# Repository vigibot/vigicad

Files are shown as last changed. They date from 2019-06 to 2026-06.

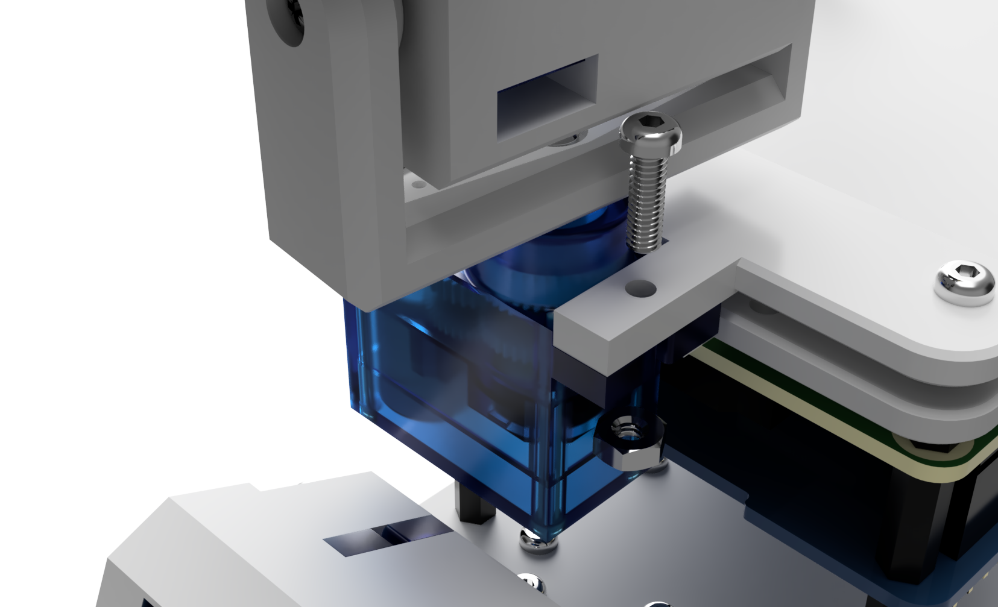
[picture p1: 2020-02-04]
images/Minus assembly/Final assembly-8.png

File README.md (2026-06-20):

# Build Your Own Vigibot Raspberry Pi Robot

## Description

[Vigibot](https://www.vigibot.com/) is a platform that enables remote control of Raspberry Pi-based robots over the Internet, with live video streaming and real-time interaction.

This repository contains the CAD files, PCB files, and documentation required to build the reference robot platform used within the Vigibot ecosystem.

## Robot Versions

### Minus 2S (Current Version)

The **Minus 2S** is the latest generation of our 4WD robot platform, featuring a gripper and a pan-tilt camera head. It has been redesigned around custom PCBs to simplify assembly, improve reliability, and provide a cleaner overall build.

Compared to the previous version, the Minus 2S uses a **2-cell (2S) Li-ion/LiPo battery architecture** and the new **Vigi UPS V3** power management board.

Key advantages of the 2S architecture include:

- Higher available power for motors and peripherals

- Lower current for the same power output, reducing voltage drops and cable losses

- Improved stability during motor acceleration and under heavy load

- Better support for power-demanding accessories such as LiDARs, USB devices, and 4G modems

- Increased efficiency of the overall power system

The integration of the **Vigi UPS V3** further enhances the platform by providing robust power management for the Raspberry Pi and onboard electronics, improving overall system stability and reliability.

### Minus 1S (Legacy / Deprecated)

The **Minus 1S** is the previous generation of the robot platform and is now considered legacy hardware.

It uses a single-cell (1S) battery architecture and an earlier power management design. While still functional, it offers lower available power and more limited expansion capabilities compared to the Minus 2S platform.

## Repository Contents

Each repository includes the resources required to build the corresponding robot platform:

- CAD files for 3D-printed parts

- PCB design files

- Assembly documentation

- Hardware resources related to the robot platform

## Notes

- This project is actively evolving.

- Additional documentation, assembly guides, and build instructions will be added over time.

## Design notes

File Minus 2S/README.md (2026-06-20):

# Build Your Own Minus 2S Robot

## Description

The **Minus 2S** is the latest generation of our 4WD mobile robot platform, featuring a robotic gripper, a pan-tilt camera head, infrared night vision, and full compatibility with the Vigibot remote-control platform.

Designed around custom PCBs, a 2S battery architecture, and the new **Vigi UPS V3**, it offers simplified assembly, improved reliability, and enhanced power capabilities compared to the previous Minus 1S platform.

All the parts required to build the robot are available in the following kit:  
[Minus 2S Kit](https://www.robot-maker.com/shop/kits-robots/284-kit-minus-2s-284.html)

## Parts List (included in the kit)

### Standard Components

- Raspberry Pi 3B+

- 32 GB microSD card

- N20 DC gear motors with pogo-pin connectors ×4

- 32 mm wheels ×4

- 2S1P battery pack

- 3 W mini speaker

- Raspberry Pi Camera with IR-cut filter

- 9 g 270° servo motor ×1

- 9 g 180° servo motors ×3

- 20 cm Raspberry Pi ribbon cable

- Raspberry Pi spacer (2×20 long female header)

### PCB Set

- Vigi UPS V3 Bottom PCB

- Audio Top PCB

- IR LED Head PCB

- Right Side PCB

- Left Side PCB

### 3D Printed Parts Set

- Minus 2S Base

- Battery Holder

- Head and Gripper Mount

- Gripper Body

- Right Gripper Finger

- Left Gripper Finger

- Head Mount

- Head

### Screws and Standoffs Set

- M2.5 × 5 mm nylon male standoffs ×4

- M2.5 × 4 mm nylon screws ×4

- M2.5 nylon nuts ×4

- M2 × 5 mm nylon male standoffs ×2

- M2 × 6 mm metal screws ×13

- M2 × 14 mm metal screws ×6

- M2 × 12 mm metal screws ×2

- M2 × 8 mm metal screws ×7

- M2 nylon nuts ×6

## Optional Add-ons

You can customize your robot with many accessories :

- [LED Rotating Beacon](https://www.robot-maker.com/shop/composants/489-gyrophare-led-489.html)

- [LD06 LiDAR](https://www.robot-maker.com/shop/capteurs/468-lidar-ld06-468.html)

- [Mecanum wheels 48mm](https://www.robot-maker.com/shop/elements-mecaniques/471-roues-mecanum-48mm-de-diametre-471.html)

- Magnetic charging station 
  
  - [Magnetic cable](https://www.robot-maker.com/shop/alimentation/335-cable-usb-magnetique.html)
  - [Magnetic USB C Plug](https://www.robot-maker.com/shop/alimentation/336-embout-magnetique-micro-usb-336.html)

- 4G USB modem with right-angle USB adapter and 3D-printed holder

## Notes

- This project is currently a work in progress. Additional documentation and assembly instructions will be added soon.

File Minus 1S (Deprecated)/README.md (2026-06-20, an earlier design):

# Make your own Vigibot.com raspberry PI robot

## Minus Raspberry PI robot CAD files

### All pieces assembled for the standard Vigibot

### Parts list

#### Core assembly

- Raspberry PI 2 / Raspberry PI 3 / Raspberry PI 3 A+ / Raspberry PI 3 B+ / Raspberry PI 4

- An aftermarket *wide-angle lens* camera module v1 clone is highly recommended
  
  - The "genuine" camera module v1 or v2 use pinhole lens and are bad for first person view piloting
  - There is only one camera module v1 clone that combines a *wide-angle lens* and a motorized IR-cut filter at time of writing
    - https://www.robot-maker.com/shop/capteurs/311-camera-raspberry-pi.html  (fast delivery)
    - https://www.aliexpress.com/item/32957419294.html
  - It is better to have the *wide-angle lens* than the motorized IR-cut filter without the wide-angle lens

- 30cm Raspberry PI camera cable
  
  - https://www.robot-maker.com/shop/composants/329-nappe-raspberry-pi.html#/92-longueur-30cm

- A reliable Raspberry PI UPS hat board, there is only one at time of writing
  
  - The Geekworm / U-geek UPS Hat V3
    - https://www.amazon.fr/gp/product/B089NF1NHS
    - https://fr.aliexpress.com/item/4001113371912.html

- 1S Batterie with BMS included
  -

- 3D printed parts, screws, nuts and standoffs 
  
  - Full kit : https://www.robot-maker.com/shop/kits-robots/425-kit-chassis-4wd-minus-425.html
  - List :
    - 3D printed parts : 4  ( Top, middle, bottom and rear plate )
    - 12mm length M2.5 male standoffs between the Raspberry PI and UPS hat board : 4
    - 25mm length M2.5 male standoffs between the UPS hat board and middle plate : 4
    - 10mm length M2.5 female standoffs between the middle plate and bottom plate : 4
    - 5mm length M2.5 male standoffs between the Raspberry PI board and top plate : 4
    - 6 mm M2.5 screw : 10 ( 4 top plate / 4 bottom plate / 2 middle plate)
    - 8 or 10 mm M2.5 screw to fix motor board : 2 
    - M2.5 nut : 6 ( 4 for the motor board / 2 middle plate)
    - 8mm length M2 screw to fix the back plate on the middle plate : 3 
    - M2 nut : 3

#### Motorization

- Four Pololu 100:1 micro metal gearmotor HP 6V
  - https://www.robot-maker.com/shop/moteurs-et-actionneurs/384-moteur-pololu-300-rpm.html (provided with cable you need to solder, but can be provided soldered)
  - https://www.pololu.com/product/1101
- Four Pololu micro metal gearmotor extended bracket ( provided with screws and nuts)
  - https://www.robot-maker.com/shop/elements-mecaniques/385-support-moteur-pololu-long.html
  - https://www.pololu.com/product/1089
- Four Pololu wheel 40×7mm
  - https://www.robot-maker.com/shop/elements-mecaniques/346-roue-pololu-40mm.html  
  - https://www.pololu.com/product/1454
- Feetech 2ch motor controller (provided with cables) 
  - https://www.robot-maker.com/shop/drivers-d-actionneurs/280-driver-convertisseur-moteur-cc-servomoteur.html

#### Head assembly

- Two "SG90" type micro servo
  
  - 270° servo is highly recommended for the pan axis : 1
    
    - https://www.robot-maker.com/shop/moteurs-et-actionneurs/370-servomoteur-9g-270-370.html
  
  - 180° servo is good for the tilt axis : 1
    
    - https://www.robot-maker.com/shop/moteurs-et-actionneurs/18-servomoteur-9g-18.html

- 3D printed parts, screws, nuts and standoffs
  
  - Full kit : https://www.robot-maker.com/shop/kits-robots/88-kit-tourelle-pan-tilt-88.html
  - List :
    - 3D printed parts : 3 or 4 (Smiling head, pan plate, tilt bracket, and 4th is an optional protection to protect camera lens)
    - 10mm or 12mm length M2.5 screw  : 2 ( to fix pan plate to the rest of the robot)
    - M2.5 nut : 2
    - 5 or 6 mm M2 screw : 1 
    - 8 mm M2 screw : 2  (to fix 270° servo on the pan plate)
    - 14 or 16 mm M2 screw : 2 ( to fix 180° servo in the head)
    - 20 mm M2 screw : 4 (for camera assembly on the head)
    - M2 nut : 10 (8 for the camera, 2 to fix the servo on the pan plate)

#### Clamp assembly

- 180° servo SG90 servo : 2
  
  - https://www.robot-maker.com/shop/moteurs-et-actionneurs/18-servomoteur-9g-18.html

- 3D printed parts, screws and nuts
  
  - Full kit : https://www.robot-maker.com/shop/kits-robots/423-kit-pince-minus-423.html
  - List :
    - 3D printed parts : 4
    - 5 or 6 mm M2 screw : 1
    - 8 mm M2 screw : 3
    - 10 mm M2 screw : 1
    - 14 mm M2 screw : 5
    - M2 nut : 2

#### Lateral arms

- 180° servo SG90 servo : 2
  
  - https://www.robot-maker.com/shop/moteurs-et-actionneurs/18-servomoteur-9g-18.html

- 3D printed parts, screws and nuts
  
  - Full kit : https://www.robot-maker.com/shop/kits-robots/424-kit-bras-lateraux-minus-424.html
  - List :
    - 3D printed parts : 4 (left and right servo holder, and left and right lateral arms)
    - 8 mm M2 screw : 2 (to fix lateral arms on the servo)
    - 14 mm M2.5 screw : 2 (to fix servo holders on the rest of the robot it replaces 8mm M2.5 screws)
    - M2.5 nut : 2 (to fix servo holders on the rest of the robot, use 8mm M2.5 screws previously removed, wich was already on your robot) 
    - Note : use the long screws provided with servomotors to fix the servomotors on the servo holder

#### Charge station assembly

- A USB magnetic cable with magnetic plug
  - https://www.robot-maker.com/shop/alimentation/335-cable-usb-magnetique.html
  - https://www.robot-maker.com/shop/alimentation/336-embout-magnetique-micro-usb-336.html
- 3D printed part :
  - https://www.robot-maker.com/forum/topic/13134-station-de-charge-pour-robot-de-type-minus

#### Optionnal add ons

- 40mm fan for the top plate  https://www.amazon.fr/gp/product/B07D5QBFLK/ref=ppx_yo_dt_b_asin_title_o01_s00 ( use top plate with fan hole in this case)
- Leds to show if someone is using the robot or not
- Cables to manually control the IR led state on the camera

### Notes

- All stl files are provided, you will need 3D printer to print them. ( But if you don't have one you can buy the parts you need on Robot Maker)
- All sources files are provided. They are made on openscad. You will need The OpenSCAD open source software available at https://www.openscad.org to open or customize SCAD files
- Step files are also provided to be use as raw file material for other software if you want make modification with your own prefered software.
- This French video can help to better understand how to assemble the robot : https://youtu.be/9Eja0gG4bhI

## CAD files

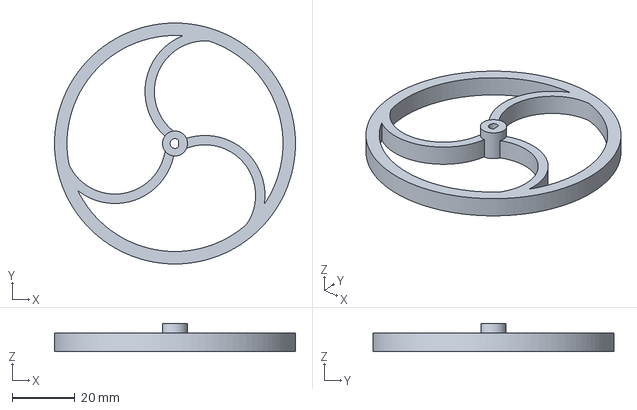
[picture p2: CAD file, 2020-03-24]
3mf/HighlyConfigurableWheelv1.32_Pascal_rev.3mf
77.0 x 77.0 x 9.00 mm

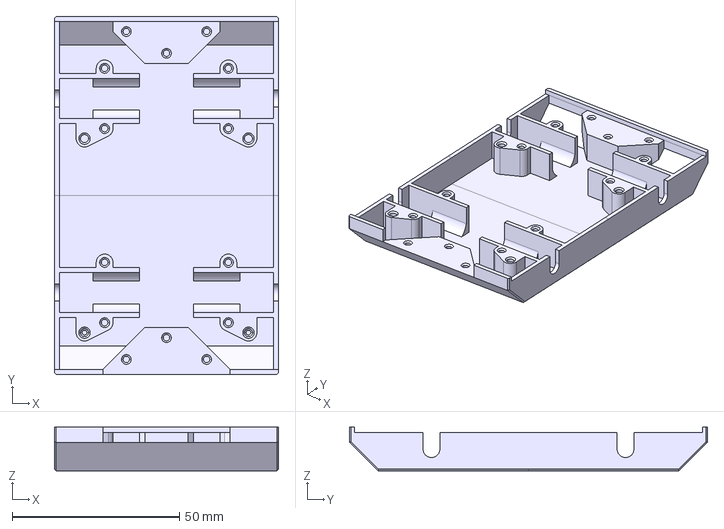
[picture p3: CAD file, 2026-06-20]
Minus 2S/3d Printed Parts/Body/Base Minus 2S.step
67.0 x 107.0 x 13.1 mm

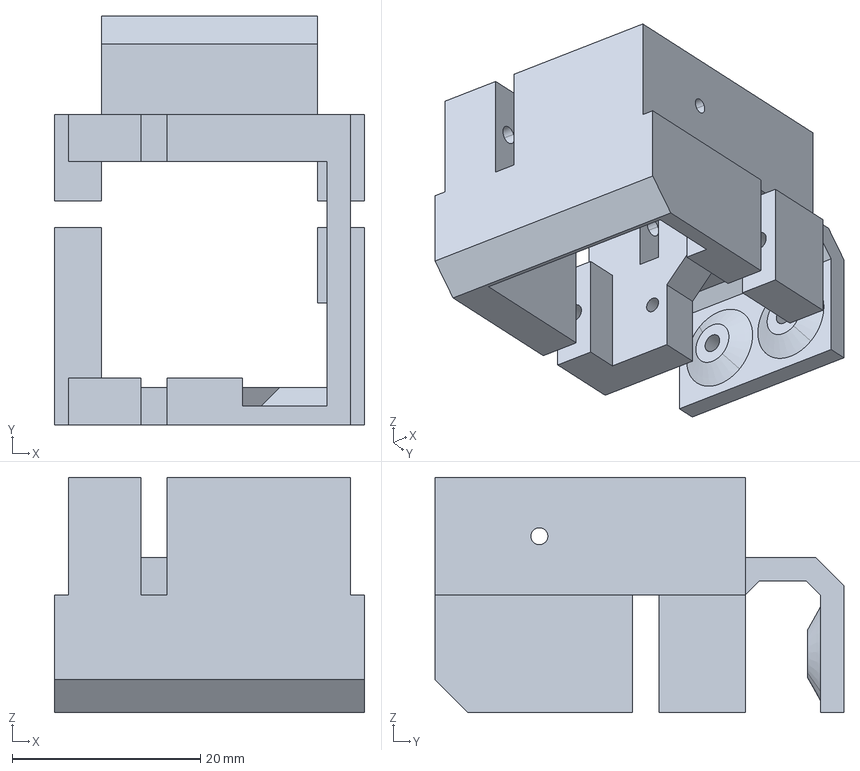
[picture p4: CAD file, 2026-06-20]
Minus 2S/3d Printed Parts/Gripper/Gripper Dual Servo Bracket.step
33.0 x 43.5 x 25.0 mm

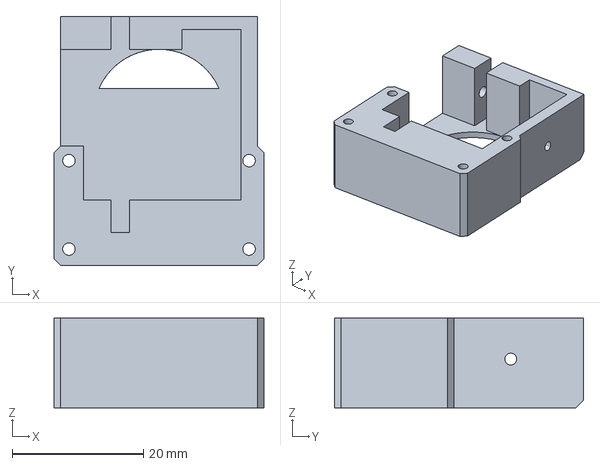
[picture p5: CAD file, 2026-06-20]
Minus 2S/3d Printed Parts/Head/Smiling Head Servo Camera Bracket.step
32.0 x 38.0 x 13.7 mm

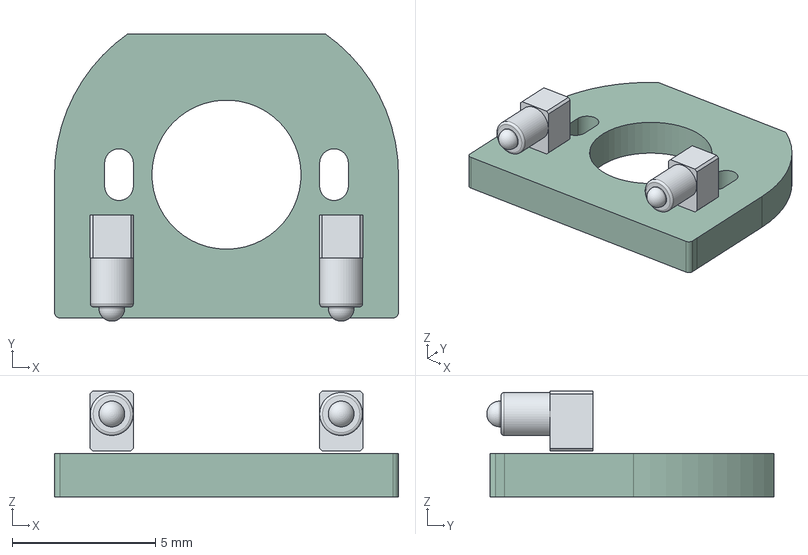
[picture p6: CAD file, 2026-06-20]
Minus 2S/Pcb Boards/N2 _PogoPin Pcb.step
12.0 x 10.0 x 3.70 mm
YZF0053 x 2
Addon_N20_motor_PCB

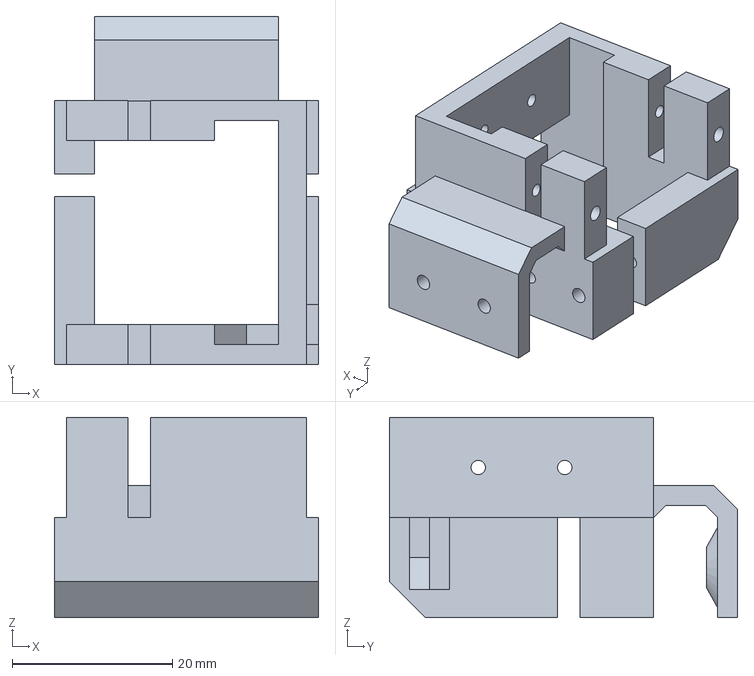
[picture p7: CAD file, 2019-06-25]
mk3s-mmu2s/BlocPince.3mf
33.0 x 43.5 x 25.0 mm

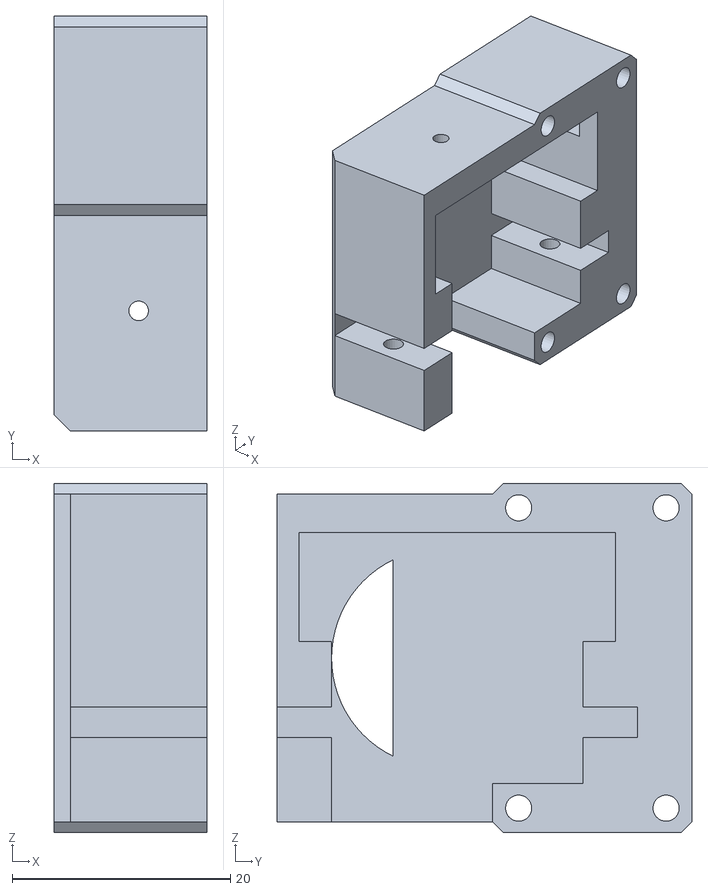
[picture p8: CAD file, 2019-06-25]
stl/BlocTeteSourire.stl
14.0 x 38.0 x 32.0

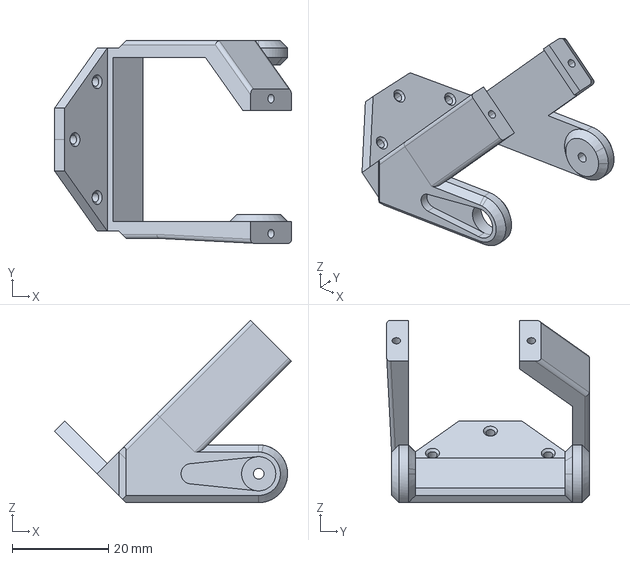
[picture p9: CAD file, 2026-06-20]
Minus 2S/3d Printed Parts/Body/Head and gripper bracket.step
49.1 x 42.0 x 37.8 mm

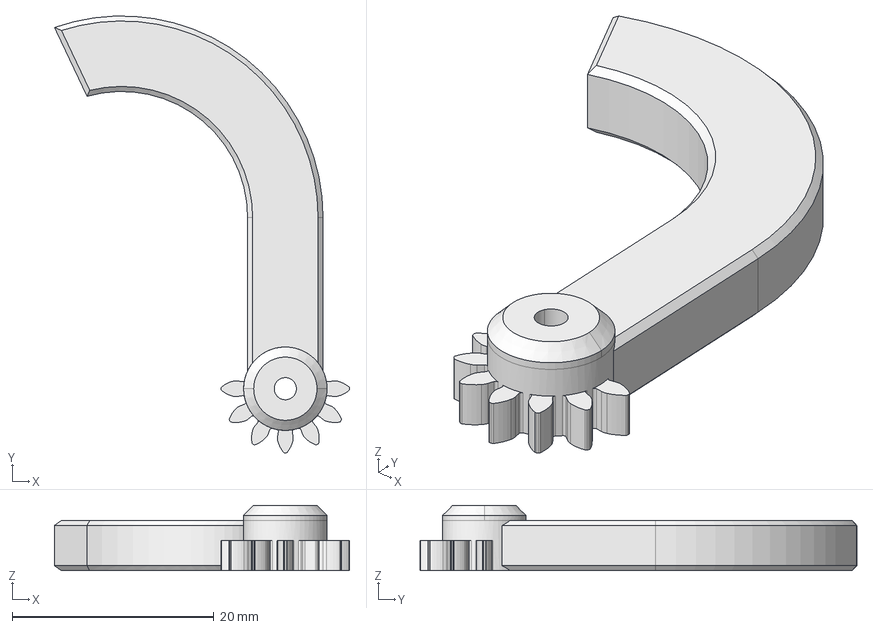
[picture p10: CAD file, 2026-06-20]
Minus 2S/3d Printed Parts/Gripper/Gripper right finger.step
29.3 x 43.3 x 6.50 mm

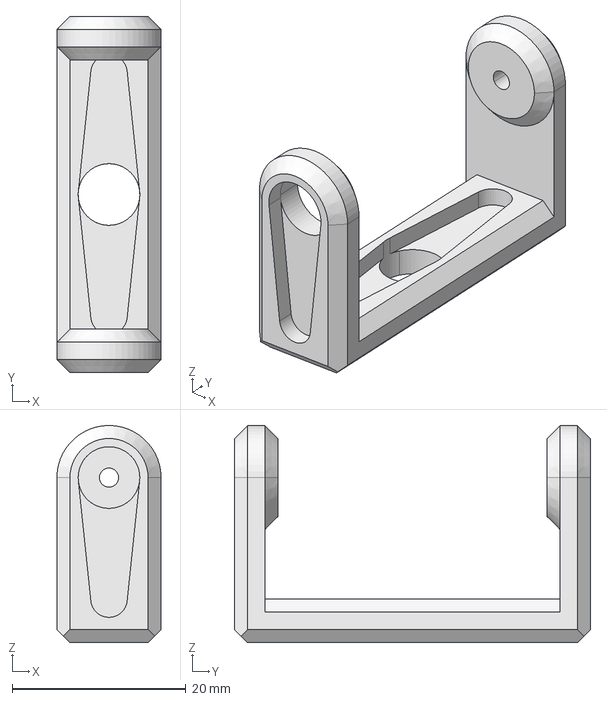
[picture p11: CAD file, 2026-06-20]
Minus 2S/3d Printed Parts/Head/Head U Bracket.step
12.0 x 41.0 x 25.0 mm

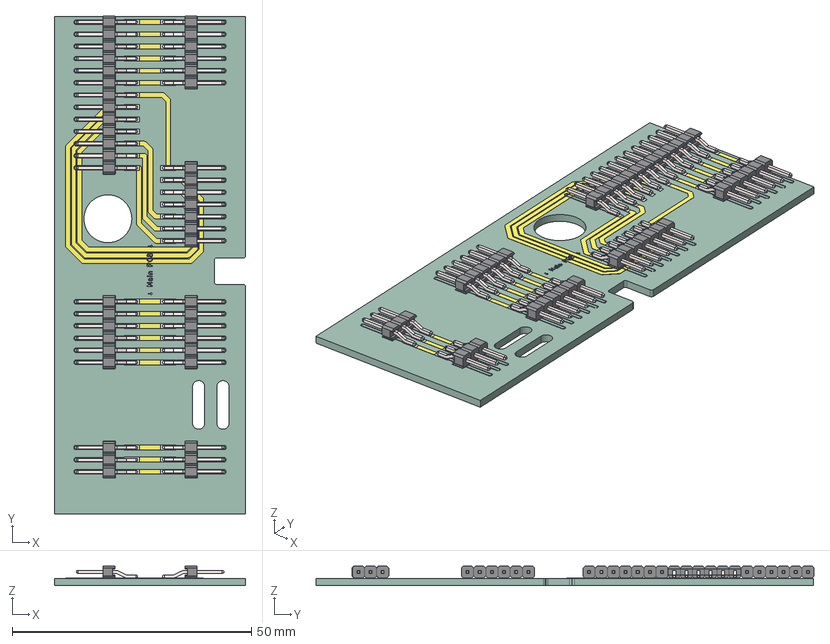
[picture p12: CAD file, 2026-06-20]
Minus 2S/Pcb Boards/Left Side Pcb.step
40.0 x 104.1 x 4.17 mm
2.54mm header SMT_6P x 4
2.54mm header SMT_7P x 2
2.54mm header SMT_3P x 2
Addon_Side_Left_copper
Addon_Side_Left_pad
Addon_Side_Left_silkscreen x 2
Addon_Side_Left_PCB

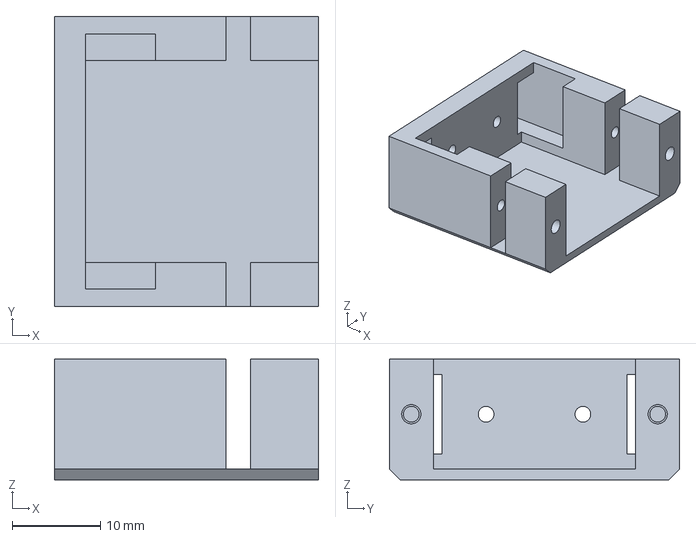
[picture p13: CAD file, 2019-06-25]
mk3s-mmu2s/BlocTete.3mf
30.0 x 33.0 x 13.7 mm

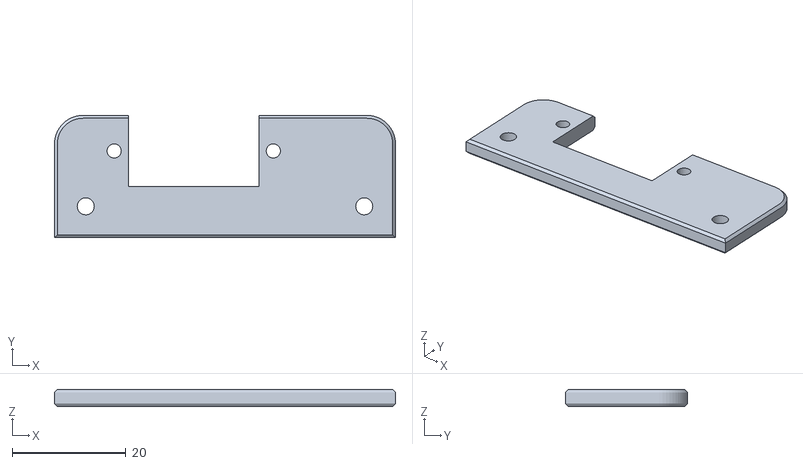
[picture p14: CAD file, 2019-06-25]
stl/SupportServo9gHaut.stl
60.0 x 21.5 x 3.00

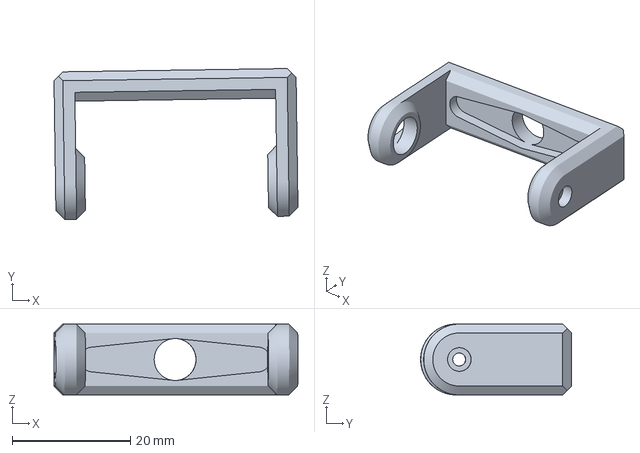
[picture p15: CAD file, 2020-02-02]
3mf/head_u_bracket.3mf
41.3 x 25.6 x 12.0 mm

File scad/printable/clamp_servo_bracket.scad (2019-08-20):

/*
 * Copyright (c) 2019, Vigibot
 * All rights reserved.
 * 
 * Redistribution and use in source and binary forms, with or without modification, are permitted provided that the following conditions are met:
 *   * Redistributions of source code must retain the above copyright notice, this list of conditions and the following disclaimer.
 *   * Redistributions in binary form must reproduce the above copyright notice, this list of conditions and the following disclaimer in the documentation and/or other materials provided with the distribution.
 * 
 * Description: OpenSCAD design for clamp holder part of Vigibot
 * Design:      Quillès Jonathan / Pascal Piazzalungua
 * Author:      Gilles Bouissac
 */

use <../lib/servo_sg90.scad>
use <../lib/servo_sg90_container.scad>
use <../lib/extensions.scad>
use <../lib/bevel.scad>
use <../lib/hardware_shop.scad>

// ----------------------------------------
//                  API
// ----------------------------------------

module clampHolder() {
    difference() {
        makeBoxes();
        mainBoxExtrude ();
        clampHolderHoles();
    }
}

// ----------------------------------------
//             Implementation
// ----------------------------------------

MAIN_SX      = servoContainerY();
MAIN_SY      = servoContainerY();
MAIN_T       = 5;   // T = Wall Thickness
MAIN_B       = 4.5; // B = Bevel

GEARBOX_SX   = 23;
GEARBOX_SY   = 10.5;
GEARBOX_SZ   = 16.5;
GEARBOX_T    = 2.5; // T = Wall Thickness
GEARBOX_BO   = 3;   // Outer Bevel
GEARBOX_BI   = 1.5; // Inner Bevel

// Centering of clamp servo container to get a square shape
CENTERING    = (servoContainerY()-servoContainerX())/2;

// ----------------------------------------
//        Implementation: main box
// ----------------------------------------

// Move the handle servo Container to its position
module handleServoTransform() {
    translate ( [ CENTERING, 0, servoContainerZ() ] )
        children();
}

// Move the clamp servo Container to its position
module clampServoTransform() {
    translate ( [
        servoContainerY(),
        servoContainerY()-CENTERING,
        servoContainerZ() ] )
        rotate ( [0,0,-90] )
        rotate ( [180,0,0] )
    children();
}

// Parts to remove from main box
module mainBoxExtrude () {

// Bevel
    translate ( [ 0, 0, MAIN_SX ])
    rotate( [0,90,0] )
    bevelCutLinear( MAIN_SX, 2*MAIN_SX, $bevel=MAIN_B );

// Cut clamp servo hole for printability
    servoHoleB = 4.25;
    translate ( [ MAIN_SX-5, MAIN_SY-MAIN_T, 0 ])
    rotate( [-90,0,0] )
    linear_extrude ( height=MAIN_T )
        polygon ( [
            [0,0],
            [-servoHeadSizeY(),0],
            [-servoHeadSizeY(),-(servoHeadSizeZ()-servoHoleB)],
            [-(servoHeadSizeY()-servoHoleB),-servoHeadSizeZ()],
            [0,-servoHeadSizeZ()]
        ]);

// Cut handle container above bottom servo for printability
    translate ( [ MAIN_SX-15.5, MAIN_SY-2.5-2.5, 12.5])
    rotate( [-90,0,0] )
    linear_extrude ( height=2.5 )
        polygon ( [
            [0,0], [2.5,0], [2.5,-2.5]
        ]);

// Wire output
    translate ( [ MAIN_SX-9, 2.5, 3.5])
    rotate( [-90,0,0] )
    linear_extrude ( height=5 )
        polygon ( [
            [0,0],
            [-4,-4],
            [-4,-9],
            [10,-9],
            [10,0],
            [0,0]
        ]);
}

// 2 stacked servo containers plus some completion on clamp servo
module mainBox() {
    // Handle servo container
    handleServoTransform()
        servoContainer( symetry=true, counterAxis=true );

    // Clamp servo container
    clampServoTransform() {
        servoContainer();

        complT = 5;
        // Complete clamp servo top for better look
        translate([-CENTERING,0,0])
            cube( [complT, servoContainerY(), servoContainerZ()] );
        // Complete clamp servo top for better look
        translate ( [ servoContainerY()-complT-CENTERING, 0, 0 ] )
            cube( [complT, servoContainerY(), servoContainerZ()] );
    }
}

// ----------------------------------------
//        Implementation: gear box
// ----------------------------------------

// Move the gear box to its position
module gearBoxTransform() {
    translate ( [ (MAIN_SX-GEARBOX_SX)/2, MAIN_SY, 0])
        children();
}

// Parts to remove from gear box
module gearBoxExtrude () {

// Middle cut
    x2 = GEARBOX_SZ-GEARBOX_T;
    x1 = x2-GEARBOX_BI;
    y3 = GEARBOX_SY-GEARBOX_T;
    y2 = y3-GEARBOX_BI;
    y1 = GEARBOX_BI;
    translate ( [ GEARBOX_SX/2-GEARBOX_SX/2, 0, 0 ])
    rotate( [0,90,0] )
    linear_extrude ( height=GEARBOX_SX )
        polygon ( [
            [0,0],
            [0,y3],
            [-x1,y3],
            [-x2,y2],
            [-x2,y1],
            [-x1-mfg(),0] // This mfg is manatory Pascal remember
        ]);

// Bevel
    translate ( [ GEARBOX_SX, GEARBOX_SY, 0 ])
    rotate( [0,0,180] )
    rotate( [0,90,0] )
    bevelCutLinear( GEARBOX_SX, 2*GEARBOX_SZ, $bevel=GEARBOX_BO );
}

// One gear stand in gear box
module clampStand () {
    rotate( [90,0,0] )
    rotate_extrude()
    polygon ( [
        [0,0], [5,0], [2.5,1.4], [0,1.4]
    ]);
}

// The box that hold the gears from clamps
module gearBox() {
     gearBoxTransform() {
        difference () {
            // main cube
            cube( [GEARBOX_SX, GEARBOX_SY, GEARBOX_SZ] );
            gearBoxExtrude ();
        }
        translate ( [ GEARBOX_SX/2, GEARBOX_SY-GEARBOX_T, servoContainerZ()/2])
            mirrorY()
            translate ( [ -servoAxisPosY(), 0, 0])
            clampStand();
    }
}

// ----------------------------------------
//        Implementation: assembly
// ----------------------------------------

// Screw holes not already made by libraries
module clampHolderHoles() {

// Clamp screws for gearBox
    translate ( [ MAIN_SX/2, servoContainerY(), servoContainerZ()/2])
        mirrorY()
        translate ( [ -servoAxisPosY(), 0, 0])
        rotate( [90,0,0] )
        screwM2Tight(MAIN_T,GEARBOX_SY);

// Servo handle screws
    // We need them again to drill added parts from mainBox()
    clampServoTransform()
        servoContainerTransform()
        servoScrewHoles();
}

// Merges boxes
module makeBoxes() {
    mainBox();
    gearBox();
}

// ----------------------------------------
//                 Showcase
// ----------------------------------------
difference() {
    clampHolder($fn=100);
    if ( 0 ) {
        %import( "../../stl/clamp_servo_bracket.stl" );
    }
}

if ( 0 ) {
    %clampHolderHoles($fn=100);
    %handleServoTransform()
        servoContainerTransform() {
            servo(30);
            servoScrewHoles();
            mirrorX()
            servoCounterAxisHole();
        }
    %clampServoTransform()
        servoContainerTransform() {
            servo(135);
        }
    %import( "../../stl/clamp_servo_bracket.stl" );
}

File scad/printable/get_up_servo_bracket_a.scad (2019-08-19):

/*
 * Copyright (c) 2019, Vigibot
 * All rights reserved.
 * 
 * Redistribution and use in source and binary forms, with or without modification, are permitted provided that the following conditions are met:
 *   * Redistributions of source code must retain the above copyright notice, this list of conditions and the following disclaimer.
 *   * Redistributions in binary form must reproduce the above copyright notice, this list of conditions and the following disclaimer in the documentation and/or other materials provided with the distribution.
 * 
 * Description: OpenSCAD design for Vigibot usb bracket
 * Design:      Quillès Jonathan / Pascal Piazzalungua
 * Author:      Quillès Jonathan
 */

use <../lib/servo_sg90.scad>
use <../lib/plates.scad>

PRECISION = 100;

$fn = PRECISION;

SERVO_BOX_Z = 12.5;
SERVO_STAND_LENGTH = 33;
PLATE_WIDTH = 3;
INTER_AXIS = 21;
OFFSET_AXIS = 1;
RADIUS = 1.5;
AXIS_HEIGHT = 18;
PLATE_HEIGHT = 9.5;
CHAMFER = 4; 

plate();
difference(){
    box();
    #servoBracketExtrude();
    translate ([INTER_AXIS + OFFSET_AXIS, 
                        0, 
                        0])
    rotate([0, 270, 0])  
                linear_extrude (INTER_AXIS)
                    polygon ( [
                        [2.6, 0], 
                        [0, 2.6], 
                        [0, 0]
                    ]);
    
    translate ([INTER_AXIS + OFFSET_AXIS, 
                        SERVO_STAND_LENGTH + PLATE_WIDTH , 
                        0])
    rotate([90, 270, 0])  
                linear_extrude (SERVO_STAND_LENGTH + PLATE_WIDTH)
                    polygon ( [
                        [2.6, 0], 
                        [0, 2.6], 
                        [0, 0]
                    ]);
}
translate ([10, 31, 0]) cube([9,3,2.5]);


// fixating plate
module plate() {
    difference() {
        translate ([-CHAMFER + OFFSET_AXIS, 
                        PLATE_WIDTH, 
                        SERVO_BOX_Z])
            rotate([90, 0, 0])  
                linear_extrude (PLATE_WIDTH)
                    polygon ( [
                        [CHAMFER, 0], 
                        [0, CHAMFER], 
                        [0, PLATE_HEIGHT],
                        [INTER_AXIS + 2 * CHAMFER, PLATE_HEIGHT], 
                        [INTER_AXIS + 2 * CHAMFER, CHAMFER], 
                        [INTER_AXIS  + CHAMFER, 0]
                    ]);
        
        // fixating holes 
        translate ([OFFSET_AXIS, 0, AXIS_HEIGHT])
            rotate([90, 0, 0])
                cylinder (r = RADIUS, h = 25, center = true);
        translate ([OFFSET_AXIS + INTER_AXIS, 0, AXIS_HEIGHT])
            rotate([90, 0, 0])
                cylinder (r = RADIUS, h = 25, center = true);
    }
}

// main body
module box() {
    translate ([INTER_AXIS/2 + OFFSET_AXIS, 
                (SERVO_STAND_LENGTH + PLATE_WIDTH)/2, 
                OFFSET_AXIS])
        {
            beveledRoundedPlate([INTER_AXIS, SERVO_STAND_LENGTH + PLATE_WIDTH, 2], 0);
            translate ([0, 0, 5.5])
                cube([INTER_AXIS, SERVO_STAND_LENGTH + PLATE_WIDTH, 12], center = true);
        }
}

// servo hole
module servoBracketExtrude() {
    translate( [
        servoBoxSizeX() - 4.25,
        servoAxisPosY() + 14.1, 
        servoBoxSizeZ()/2
    ])
        rotate([180,0,0]) {
            servo(180);
            servoScrewHoles();
        }
}

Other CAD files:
3mf/HighlyConfigurableWheelv1.32_Pascal.3mf
Minus 2S/3d Printed Parts/Body/Battery holder.step
Minus 2S/3d Printed Parts/Gripper/Gripper left finger.step
Minus 2S/Pcb Boards/Head Led Pcb.step
scad/printable/generic_servo_bracket.scad
scad/printable/head_pan_servo_bracket.scad
3mf/clamp_finger_a.3mf
3mf/clamp_finger_b.3mf
3mf/clamp_servo_bracket.3mf
3mf/clamp_u_bracket.3mf
3mf/generic_servo_bracket.3mf
3mf/get_up_servo_bracket_a.3mf
3mf/get_up_servo_bracket_b.3mf
3mf/head_pan_servo_bracket.3mf
3mf/head_servo_camera_bracket_nosmile.3mf
3mf/head_servo_camera_bracket_smile.3mf
3mf/photoresistor_cap.3mf
3mf/plate_bottom.3mf
3mf/plate_middle.3mf
3mf/plate_middle_big_wheels.3mf
3mf/plate_top_fan.3mf
3mf/plate_top_nofan.3mf
3mf/rear_protection.3mf
3mf/rear_protection_long.3mf
3mf/servo_finger_a.3mf
3mf/servo_finger_b.3mf
3mf/usb_bracket.3mf
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

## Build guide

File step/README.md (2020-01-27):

# Make your own Vigibot.com raspberry PI robot

## Raspberry PI robot STEP CAD files

### Note

- All source files are available in openscad format. 
- Source files are made with parameters for easy modification. 
- If you want make a modification it's better to make them in openscad in order to ba able to share your modified source file. 
- The OpenSCAD software available at https://www.openscad.org to open or customize SCAD files

### All pieces needed for the standard Vigibot

Liste of all Minus 3D files in step format
If you use them and make modifications, share your update. 

You can discuss about 3D model in our discord : https://discord.gg/3KrMHdp
or on the forum : https://www.robot-maker.com/forum/213-vigibot/

#### Todo

- Add non 3D printed files like wheels camera, servomotors ... 
- Make a full 3D model assembly ...

#### Done

##### All 3D printed files

- clamp_finger_a.step
- clamp_finger_b.step
- clamp_servo_bracket.step
- clamp_u_bracket.step
- generic_servo_bracket.step
- get_up_servo_bracket_a.step
- get_up_servo_bracket_b.step
- head_pan_servo_bracket.step
- head_servo_camera_bracket_nosmile.step
- head_servo_camera_bracket_smile.step
- head_u_bracket.step
- photoresistor_cap.step
- plate_bottom.step
- plate_middle.step
- plate_middle_big_wheels.step
- plate_top_fan.step
- plate_top_nofan.step
- rear_protection.step
- rear_protection_long.step
- servo_finger_a.step
- servo_finger_b.step
- usb_bracket.step

##### All standard parts 

- n20_motor_holder.step

##### Custom parts

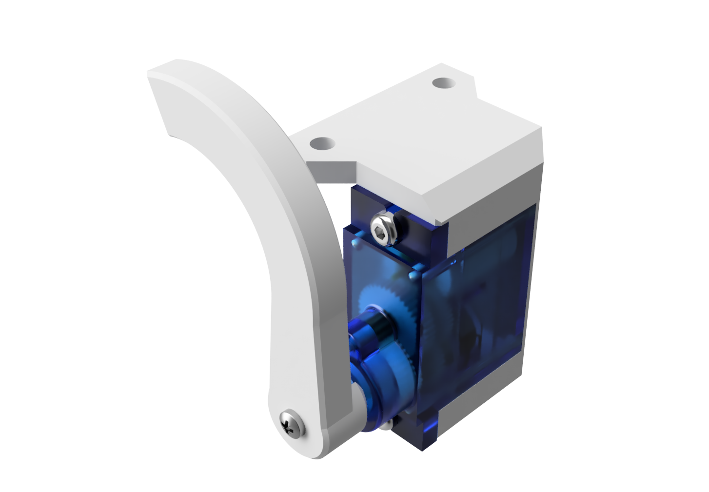
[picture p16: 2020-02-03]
images/Minus assembly/Side Arm A assembly-2.png

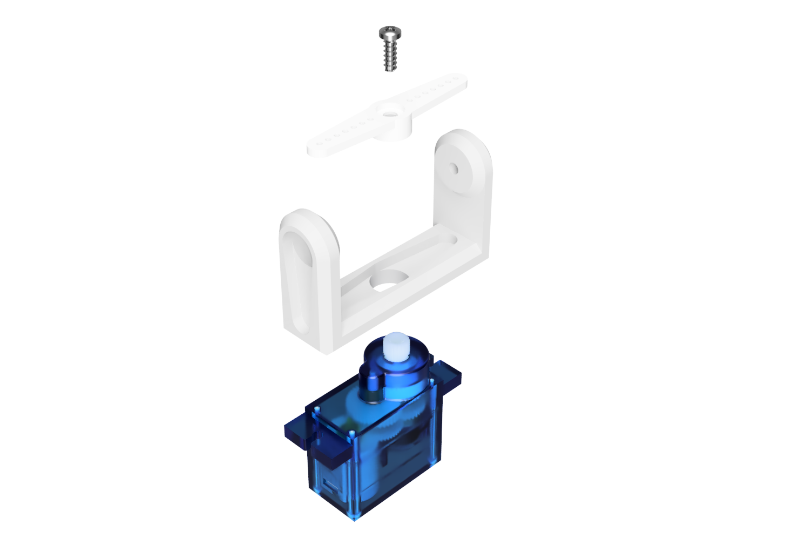
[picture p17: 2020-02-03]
images/Minus assembly/Pan turret assembly-1.png

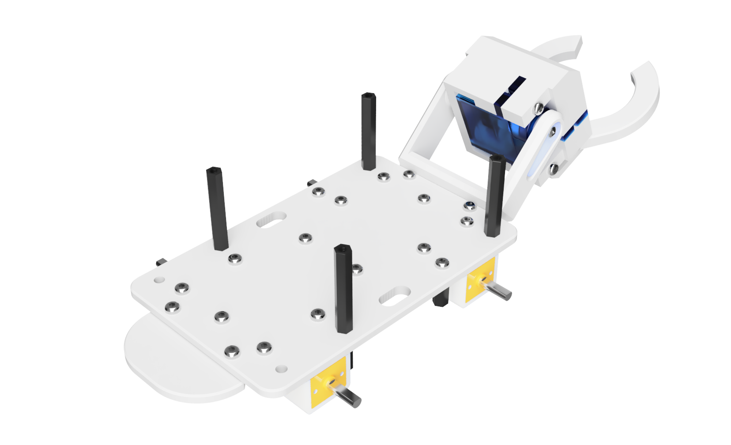
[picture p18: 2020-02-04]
images/Minus assembly/Final assembly-2.png

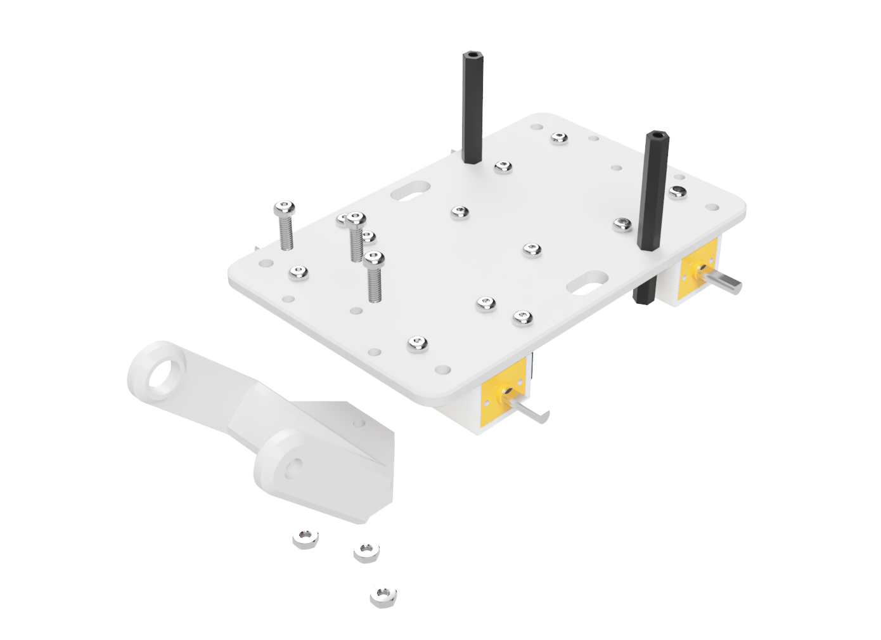
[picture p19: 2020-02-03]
images/Minus assembly/Middle plate assembly-7.png

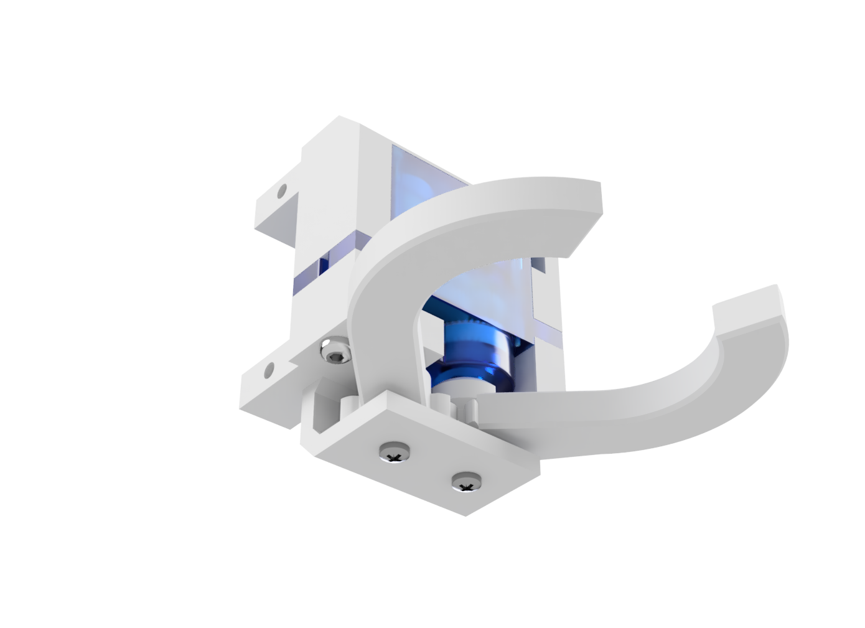
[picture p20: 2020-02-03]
images/Minus assembly/Gripper assembly-5.png

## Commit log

2019-06-25 Thanks to Gilles Bouissac for his help about OpenSCAD
    [plate-with-holes-top.3mf, plate-with-holes-top.stl, plate-with-holes.3mf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]
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2019-06-25 First try for clamp-holder design with OpenSCAD
    [clamp-holder.scad]
2019-06-25 STL export from CATIA reworked with SketchUp
    [BlocPince.skp, BlocPince.stl, BlocTete.skp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]
2019-06-25 STL export from CATIA
    [SupportServo9gBas.stl, SupportServo9gHaut.stl]
2019-06-25 fix clamp-holder printing issue
    [clamp-holder.scad]
2019-06-25 Slicing the clamp holder
    [clamp-holder.3mf, clamp-holder.stl]
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2019-06-25 Add first version of clamps with OpenSCAD
    [clamp.scad]
2019-06-26 Update clamp.scad
    12 teeth in order to have a "standard" integer number, symmetrical wedge improvement and .stl file references corrected
    [clamp.scad]
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2019-06-28 Create smilingHead.scad
    OpenSCAD design for the smiling pan & tilt smiling head, part of the Vigibot robot "Minus"
    [smilingHead.scad]
2019-06-30 Slicing the smiling head
    [smilingHead.3mf, smilingHead.stl]
2019-06-30 Slicing the bottom cover
    [PlaqueDessousProtection.3mf]
2019-06-30 Slicing the U-shaped part for smiling head
    [UDroit25mm.3mf]
2019-06-30 Smiling head with standard space for wires
    [smilingHead.scad]
2019-07-02 servoBracket.scad
    Symmetrical multipurpose brackets for standard 9G servomotors with counter axis holes.
    [servoBracket.scad]
2019-07-02 Minors improvements on the smiling head
    180° flip to directly generate a .stl file with the good standard printing orientation + minors typos esthetics corrections.
    [smilingHead.scad]
2019-07-06 Archiving old old SketchUp files
    [BlocTete.3mf, BlocTete.skp, BlocTete.stl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]
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2019-07-06 Slicing the servo bracket and the smiling head
    [servoBracket.3mf, servoBracket.stl, smilingHead.3mf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]
2019-07-16 Adding holes for top fan
    [plate-with-holes.scad]
2019-07-16 Slicing the top plate with fan holes
    [plate-with-holes-top-fan.3mf, plate-with-holes-top-fan.stl]
2019-07-19 Flipping the USB support
    [SupportUSB.3mf]
2019-07-24 Slicing the pan servo bracket for camera head
    [SupportServo9gBas.3mf]
2019-07-25 Flipping the pan servo bracket
    [SupportServo9gBas.3mf]
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2019-07-26 Make a hole on the pan servo bracket
    [SupportServo9gBas.skp, SupportServo9gBas.stl]
2019-07-26 Revert "Slicing the pan servo bracket for camera head"
    This reverts commit 690ac5807fdf2d6b3938a97e3563c08c60afe5e4.
    [SupportServo9gBas.3mf]
2019-07-26 Revert "Make a hole on the pan servo bracket"
    This reverts commit c8892455326a4f91a96782bf7c08873a8ff619f6.
    [SupportServo9gBas.skp, SupportServo9gBas.stl]
2019-07-26 Revert "Flipping the pan servo bracket"
    This reverts commit b39481e5c55e719b619d4f1ee7e696dcbd6cd8ad.
    [SupportServo9gBas.3mf]
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2019-08-06 Massive renaming of files - The end - With todo.txt files
    [clamp_u_bracket.3mf, head_u_bracket.3mf]
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2019-08-06 Added missing scad files
    [clamp_u_bracket.scad, photoresistor_cap.scad, plate_bottom.scad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]
2019-08-07 First comit
    Part designed for two bearings size 2*5*2.5
    [station_link.scad]
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2019-08-07 Slicing Gilles OpenSCAD, last todo: clamp_u_bracket holes and head_pan_servo_braket part
    [head_u_bracket.3mf, head_u_bracket.stl, photoresistor_cap.3mf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]
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2019-08-08 library already included
    Servo lib is already included in u bracket lib.
    [clamp_u_bracket.scad]
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2019-08-08 0.1 mm correction
    [head_pan_bracket.scad]
2019-08-08 Small size of the tool bracket is a little larger
    As suggested by Pascal, it may be better to keep the same angle instead of the same small size on tool brackets for an esthetical reason.
    [head_pan_bracket.scad]
2019-08-08 Avoid manifold on servo
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2019-08-09 Parts must be flipped before printing (if needed for textured bed)
2019-08-09 Slicing flipped plate_top_fan and head_pan_servo_braket
    [head_pan_servo_braket.3mf, head_pan_servo_braket.stl, plate_top_fan.3mf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]
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2019-08-10 Control bevel and mfg globally with $bevel and $mfg
    [head_pan_servo_braket_2.scad, photoresistor_cap.scad, usb_bracket.scad]
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2019-08-11 Tool plate ok now and used in usb plate
    [clamp_finger_a.scad, clamp_finger_b.scad, clamp_servo_bracket.scad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]
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2019-08-12 fix missing parameters
    [head_pan_servo_bracket.scad, head_pan_servo_bracket_1.scad]
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2019-08-17 Add a servo to allow robots to get up
    [get_up_servo_bracket.scad]
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2019-08-18 Add bevel and use servo lib
    Also adding some comments ...
    [get_up_servo_bracket.scad]
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2019-08-18 fix bevel bug on usb_bracket and ... more stuff
    [clamp_u_bracket.scad, get_up_servo_bracket_a.scad, rear_protection.scad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]
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2019-08-20 Standardize the space for wires to 2.5mm TODO use the servo library
    [generic_servo_bracket.scad, head_servo_camera_bracket.scad]
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2019-08-20 clamp_servo_bracket reworked
    [clamp_servo_bracket.scad]
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2019-08-20 Small bevels are only for scratches resistance of external edges
    [clamp_u_bracket_1.scad]
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2019-08-21 Purge all MK3SMMU2S files with bad fan speed
    [clamp_finger_a.3mf, clamp_finger_b.3mf, clamp_servo_bracket.3mf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]
2019-08-21 All thin wall thickness must be equal to 1.2mm
    [generic_servo_bracket.scad]
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2019-09-06 New head without smile and mirrored for better robot look
    [head_servo_camera_bracket_nosmile.scad, head_servo_camera_bracket_smile.scad]
2019-09-06 fix sidewire on head_servo_camera_bracket_nosmile
    [head_servo_camera_bracket_nosmile.scad]
2019-09-06 Slicing the nosmile mirrored head for new Jonathan PI camera cable
    [head_servo_camera_bracket_nosmile.3mf]
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2019-09-12 Adding a 2mm offset to pass wires of head assembly
    [head_pan_servo_bracket.scad]
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2019-10-09 Slicing the new middle plate for big wheels
    [plate_middle_big_wheels.3mf, plate_middle_big_wheels.stl]
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2020-01-27 Delete file with wrong name
    The correct file is already in the directory.
    [get_up_servo_bracket_b.step.stp]
2020-01-27 Add standard long n20 motor holder
    This is a standard part that can be 3D printed if you don't have it. This long holder protects the motor's gears.
    [n20_motor_holder.step]
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2020-01-29 add pololu wheel 40x7mm
    Standard white pololu wheel 40*7mm
    [pololu_wheel_40x7mm.step]
2020-01-29 Adding standard parts
    Adding Feetech motor board, Pololu motor and wheel.
    [feetech_2ch_board.step, pololu_n20_motor.step, pololu_wheel_40x7mm.step]
2020-02-02 Correct a length error on the head U bracket
2020-02-02 Slicing the head U-shaped bracket with correct height
    [head_u_bracket.3mf, head_u_bracket.step, head_u_bracket.stl]
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2020-03-24 Adding Highly Configurable Wheel by Alex Franke www.theFrankes.com
    [HighlyConfigurableWheelv1.32.scad, HighlyConfigurableWheelv1.32_Pascal.3mf, HighlyConfigurableWheelv1.32_Pascal.scad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]
2020-07-15 Bad STL, missing 2mm offset to pass wires of head assembly
    [head_pan_servo_bracket.stl]
2026-06-20 Set Minus 1S as deprecated
    Minus 2S is replacing Minus 1S
    [HighlyConfigurableWheelv1.32.scad, HighlyConfigurableWheelv1.32_Pascal.3mf, HighlyConfigurableWheelv1.32_Pascal.scad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]
2026-06-20 Create Minus 2S Folder
    TODO:
    - Add screws, nuts, and hex standoffs to the CAD assembly
    - Add assembly instructions
    - Add more photos and renderings
    - Export all standard part files
    - Add optional accessories and customization parts
    [Base Minus 2S.step, Battery holder.step, Gripper Dual Servo Bracket.step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]
